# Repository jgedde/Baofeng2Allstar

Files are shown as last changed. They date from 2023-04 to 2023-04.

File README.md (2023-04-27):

# Baofeng2Allstar

This project allows one or two Baofeng HT's to be connected to a Raspberry Pi Allstar node.  One HT can be connected to make a hotspot.  Two can be connected to make a full-duplex hotspot or a mini-repeater for event or emergency use.

The premise behind this project was to make something "plug and play" with no required modifications to either the Baofeng HTs or the Allstar node's USB sound FOB.

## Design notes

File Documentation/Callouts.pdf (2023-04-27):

1 | 2

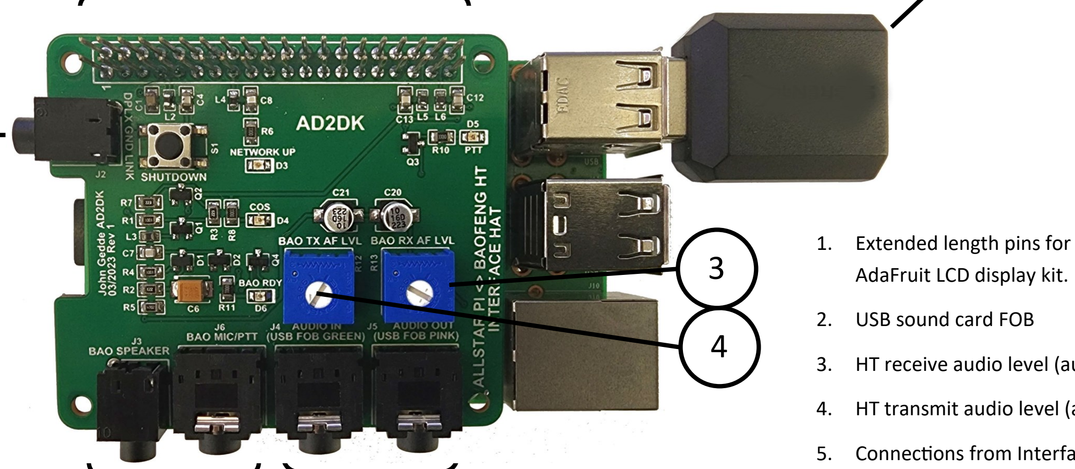
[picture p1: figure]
AdaFruit LCD display kit.; 2. USB sound card FOB

6 | 5

7

1. Extended length pins for additional compatible hats. For example,
3. HT receive audio level (audio level sent from Allstar node.)
4. HT transmit audio level (audio level sent to HT from Allstar node.)
5. Connections from Interface Hat to USB sound card. Both connectors are three conductor (stereo) 1/8 in. (3.5mm) phone jacks.
6. Connections from Interface Hat to one or two HTs. Speaker connector is 2.5mm stereo phono jack. Mic/PTT connector is 1/8 in. (3.5mm) phono jack.
7. Ground link for use with two HTs (see text.) Connector is 2.5mm stereo phone jack.

AD2DK 4/26/2023

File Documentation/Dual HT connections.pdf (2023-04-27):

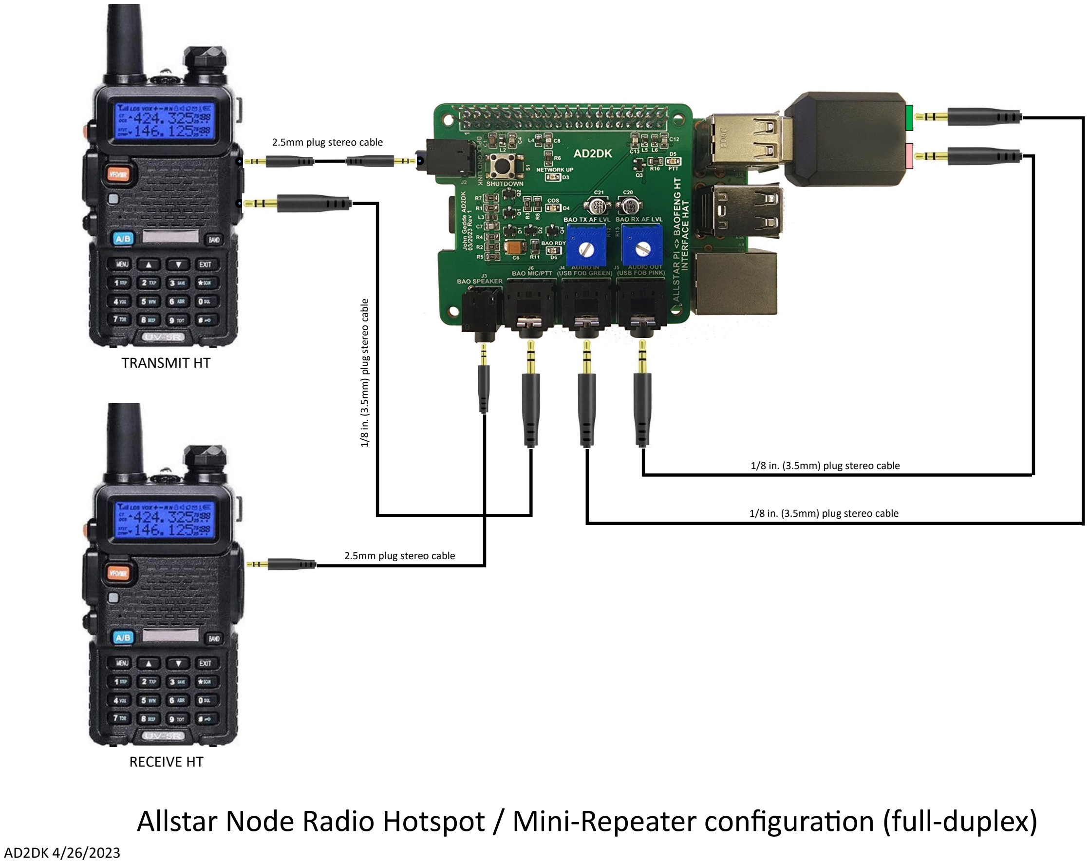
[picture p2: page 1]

1/8 in. (3.5mm) plug stereo cable

1/8 in. (3.5mm) plug stereo cable

1/8 in. (3.5mm) plug stereo cable

2.5mm plug stereo cable

## AD2DK 4/26/2023

# Allstar Node Radio Hotspot / Mini-Repeater configuration (full-duplex)

2.5mm plug stereo cable

## TRANSMIT HT

## RECEIVE HT

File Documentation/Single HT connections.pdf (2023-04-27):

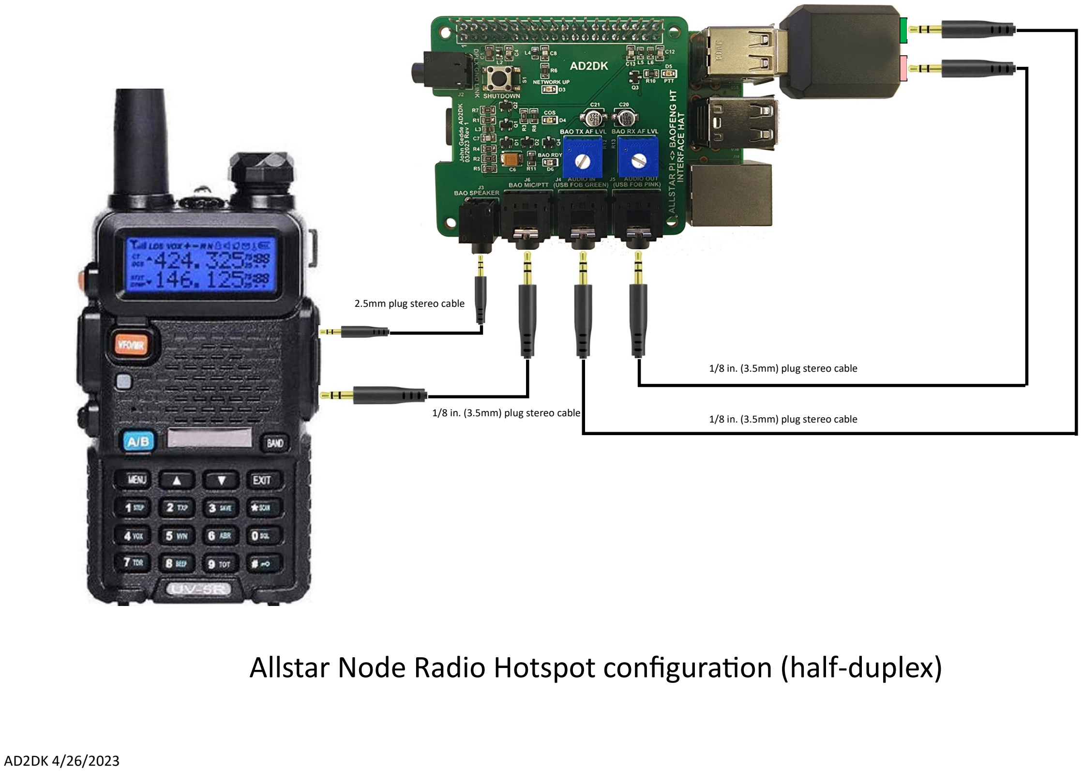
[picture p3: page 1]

1/8 in. (3.5mm) plug stereo cable

1/8 in. (3.5mm) plug stereo cable | 1/8 in. (3.5mm) plug stereo cable

2.5mm plug stereo cable

# Allstar Node Radio Hotspot configuration (half-duplex)

## AD2DK 4/26/2023

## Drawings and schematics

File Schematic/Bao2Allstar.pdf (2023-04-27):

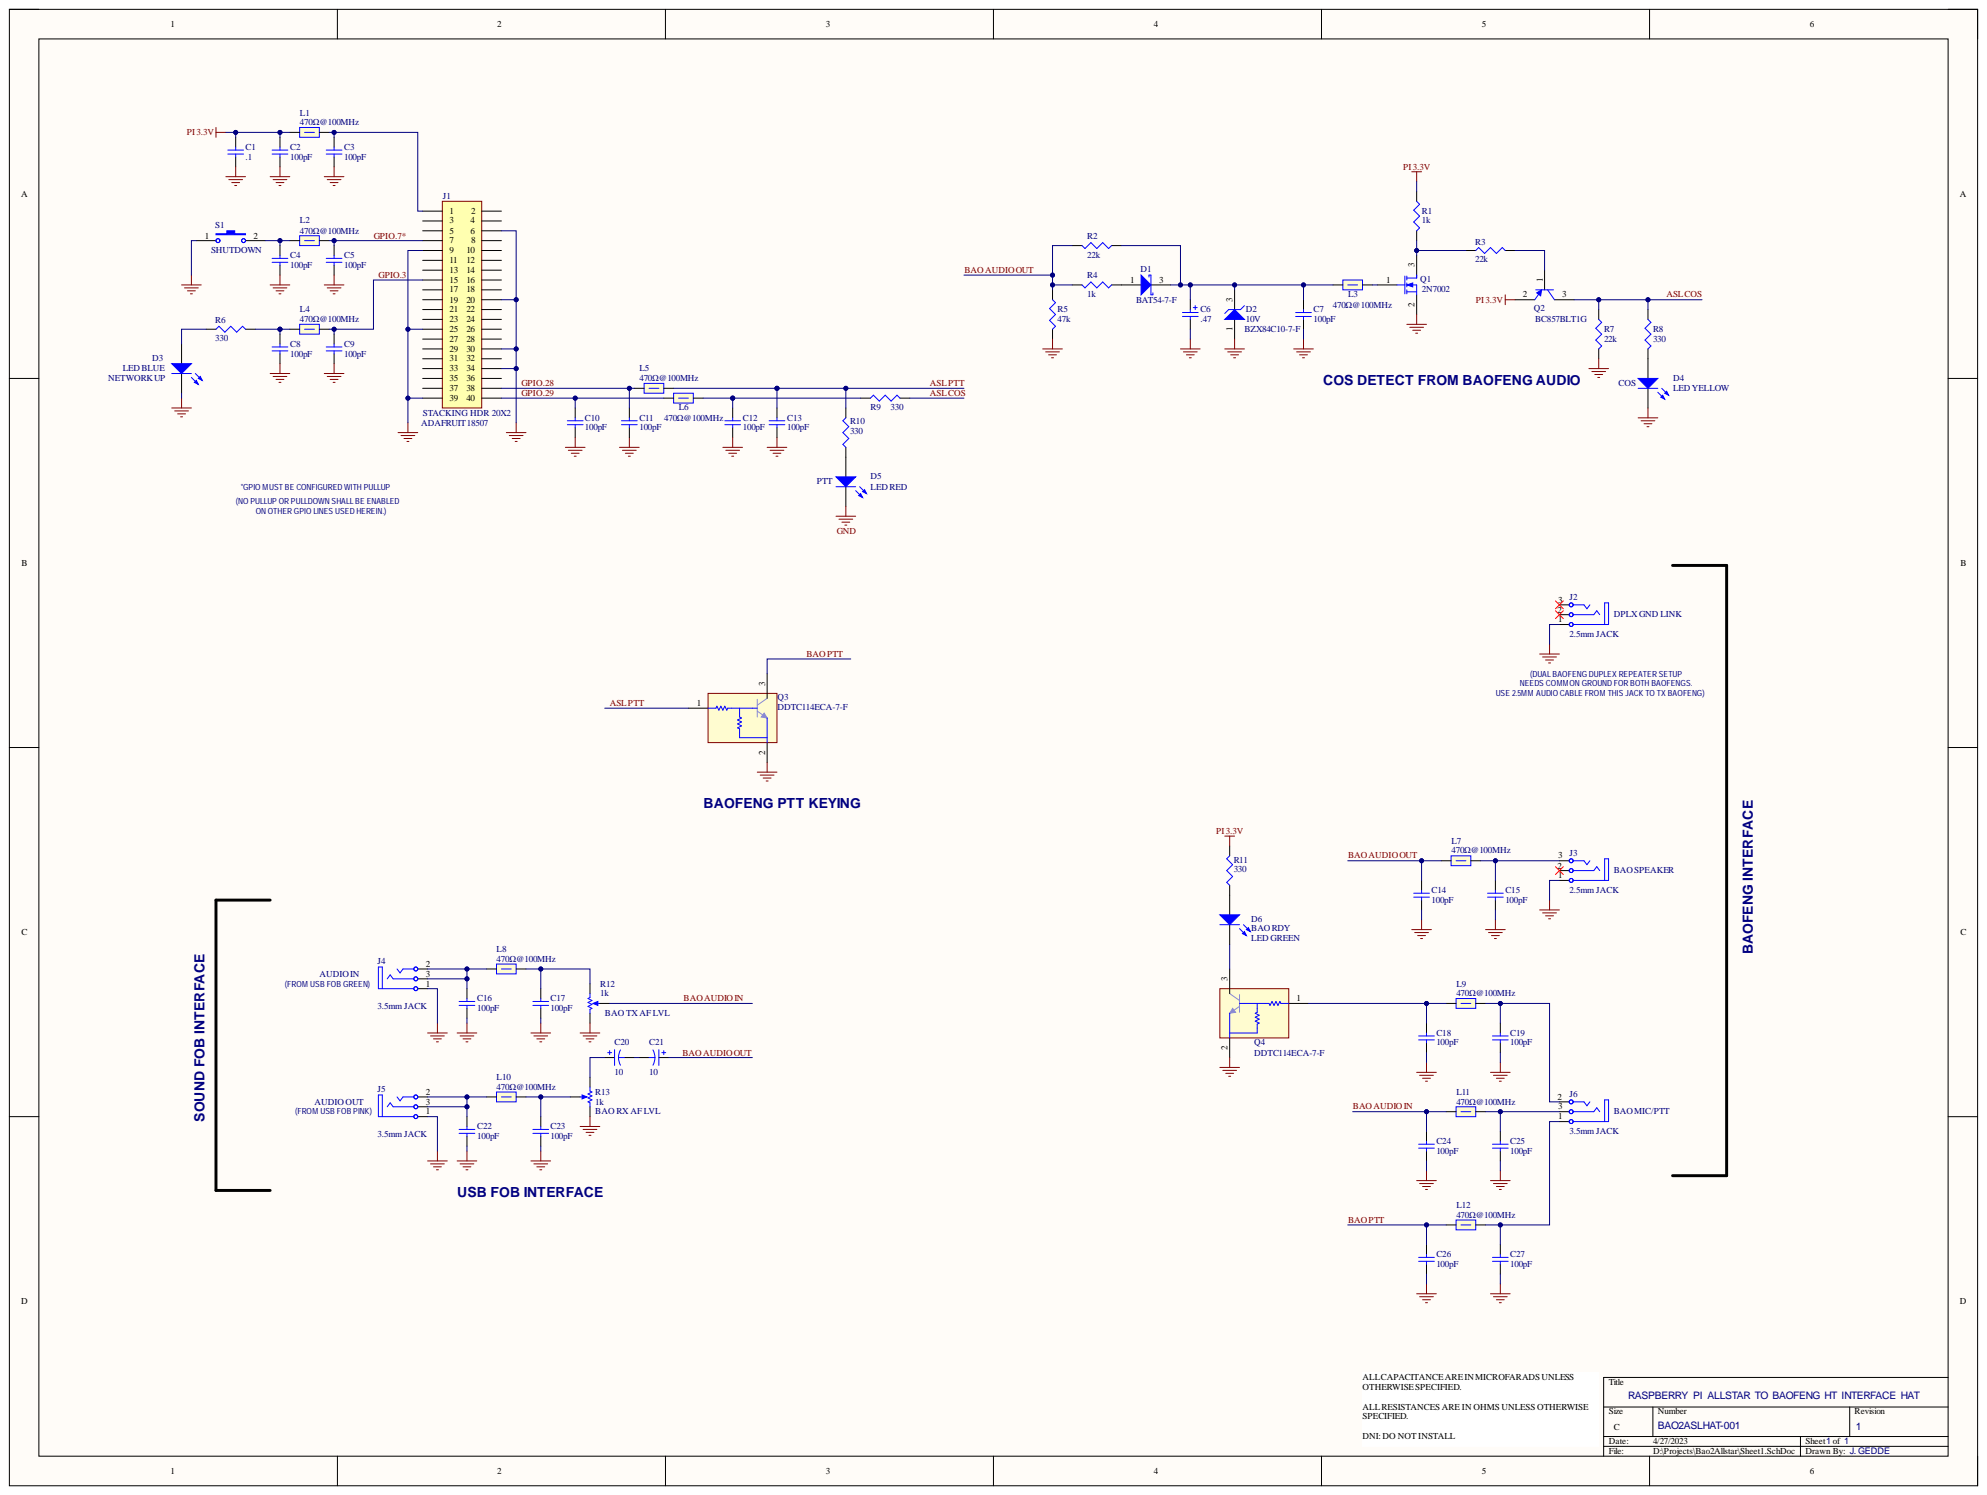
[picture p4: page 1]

*GPIO MUST BE CONFIGURED WITH PULLUP
(NO PULLUP OR PULLDOWN SHALL BE ENABLED
ON OTHER GPIO LINES USED HEREIN.)

(DUAL BAOFENG DUPLEX REPEATER SETUP
NEEDS COMMON GROUND FOR BOTH BAOFENGS.

USE 2.5MM AUDIO CABLE FROM THIS JACK TO TX BAOFENG)

(FROM USB FOB GREEN)

BAO TX AF LVL 100pF

AUDIOOUT
(FROM USB FOB PINK)

Title
RASPBERRY PI ALLSTAR TO BAOFENG HT INTERFACE HAT

ALLRESISTANCES ARE IN OHMS UNLESS OTHERWISE
SPECIFIED.

DNI: DO NOT INSTALL

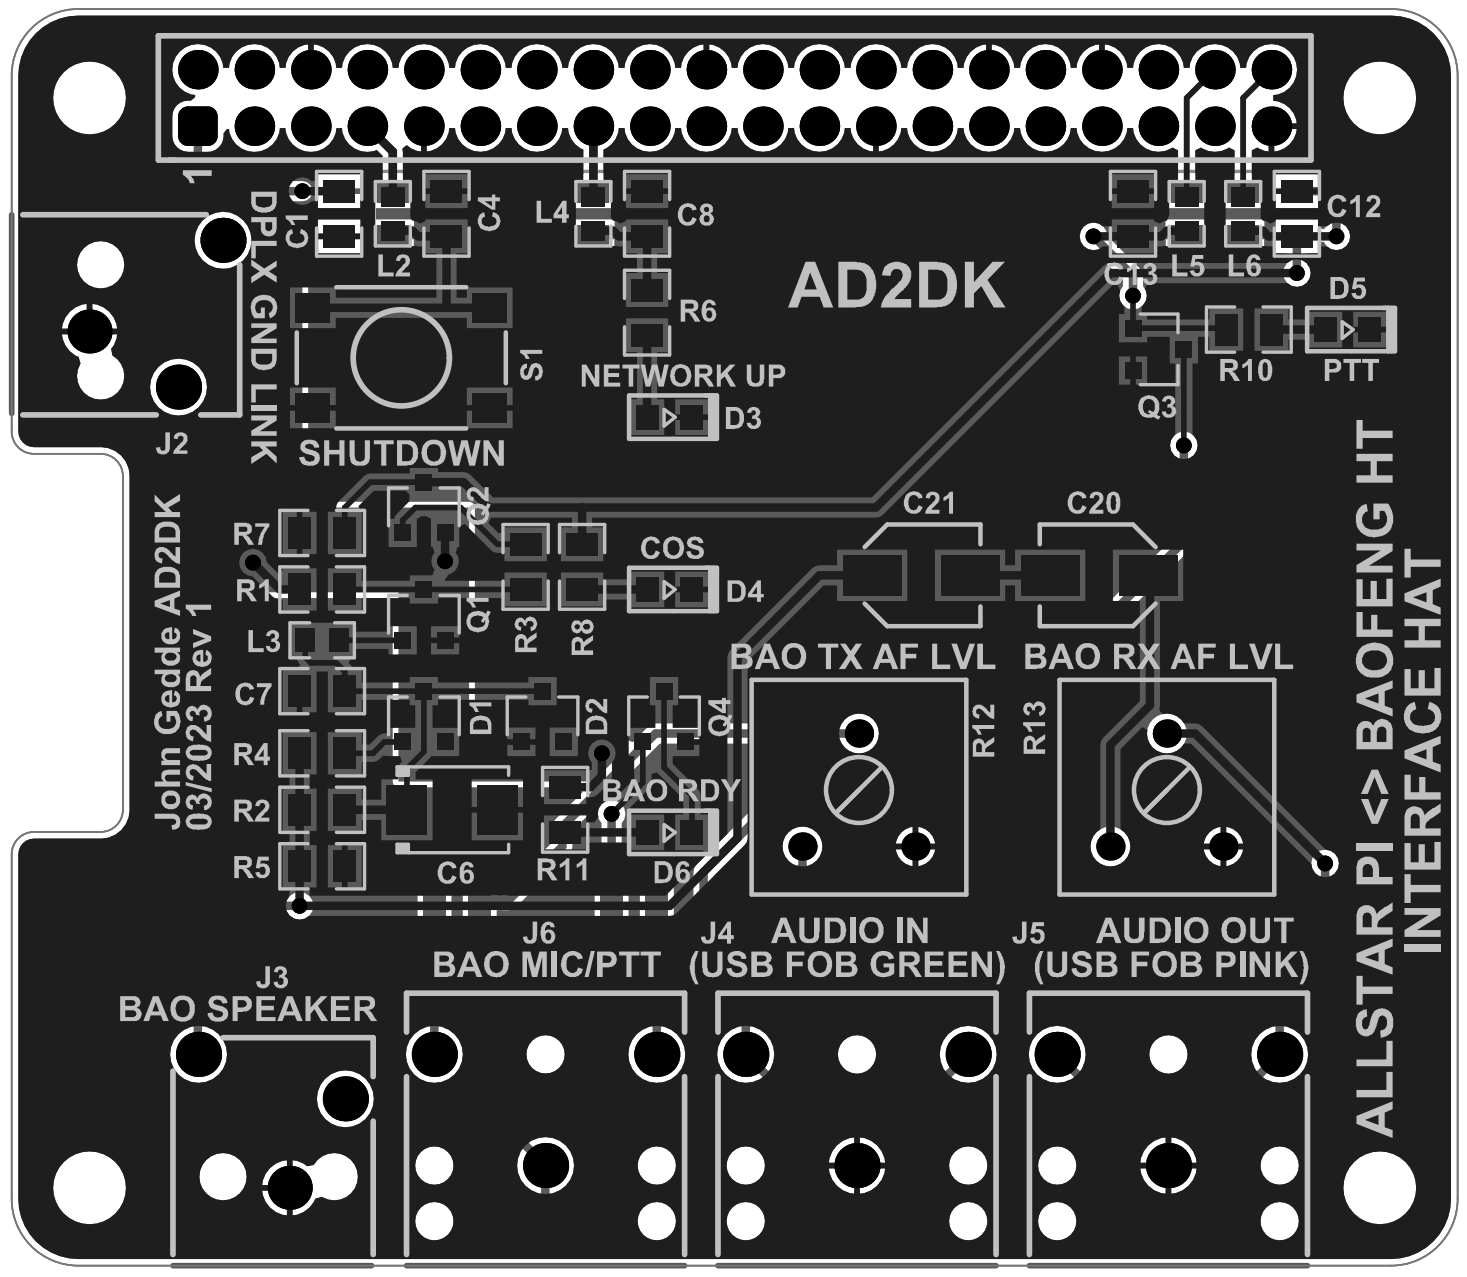
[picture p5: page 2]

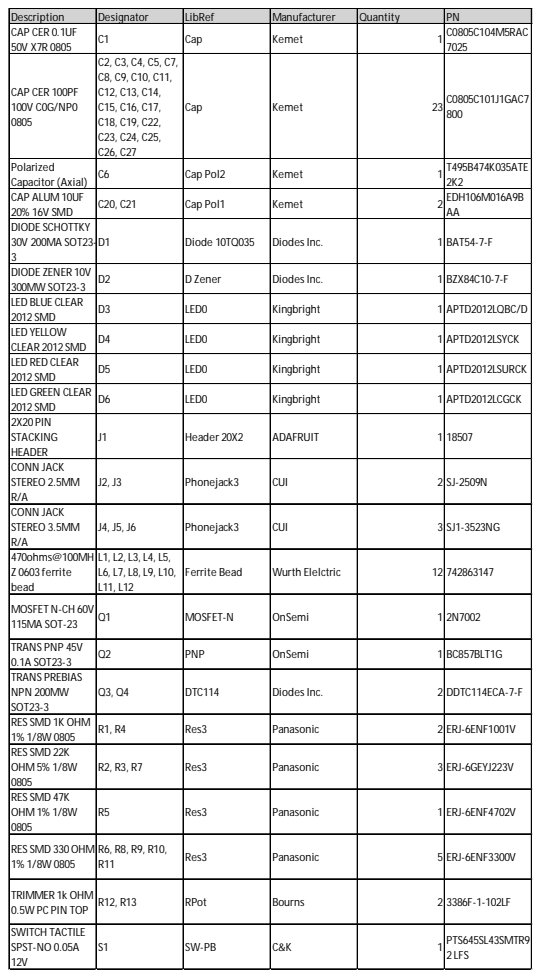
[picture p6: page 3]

Description | Designator | LibRef | Manufacturer | Quantity | PN
CAP CER 0.1UF 50V X7R 0805 | C1 | Cap | Kemet | 1 C0805C104M5RAC | 7025

CAP CER 100PF 100V C0G/NP0 0805 | C2, C3, C4, C5, C7, C8, C9, C10, C11, C12, C13, C14, C15, C16, C17, C18, C19, C22, C23, C24, C25, C26, C27 | Cap | Kemet | 23 C0805C101J1GAC7 | 800

Polarized Capacitor (Axial) | C6 | Cap Pol2 | Kemet | 1 T495B474K035ATE | 2K2

CAP ALUM 10UF 20% 16V SMD | C20, C21 | Cap Pol1 | Kemet | 2 EDH106M016A9B | AA

DIODE SCHOTTKY 30V 200MA SOT23-3 | D1 | Diode 10TQ035 | Diodes Inc. | 1 BAT54-7-F

DIODE ZENER 10V 300MW SOT23-3 | D2 | D Zener | Diodes Inc. | 1 BZX84C10-7-F

LED BLUE CLEAR 2012 SMD | D3 | LED0 | Kingbright | 1 APTD2012LQBC/D

LED YELLOW CLEAR 2012 SMD | D4 | LED0 | Kingbright | 1 APTD2012LSYCK

LED RED CLEAR 2012 SMD | D5 | LED0 | Kingbright | 1 APTD2012LSURCK

LED GREEN CLEAR 2012 SMD | D6 | LED0 | Kingbright | 1 APTD2012LCGCK

2X20 PIN STACKING HEADER | J1 | Header 20X2 | ADAFRUIT | 1 18507

CONN JACK STEREO 2.5MM R/A | J2, J3 | Phonejack3 | CUI | 2 SJ-2509N

CONN JACK STEREO 3.5MM R/A | J4, J5, J6 | Phonejack3 | CUI | 3 SJ1-3523NG

470ohms@100MH Z 0603 ferrite bead | L1, L2, L3, L4, L5, L6, L7, L8, L9, L10, L11, L12 | Ferrite Bead | Wurth Elelctric | 12 742863147

MOSFET N-CH 60V 115MA SOT-23 | Q1 | MOSFET-N | OnSemi | 1 2N7002

TRANS PNP 45V 0.1A SOT23-3 | Q2 | PNP | OnSemi | 1 BC857BLT1G

TRANS PREBIAS NPN 200MW SOT23-3 | Q3, Q4 | DTC114 | Diodes Inc. | 2 DDTC114ECA-7-F

RES SMD 1K OHM 1% 1/8W 0805 | R1, R4 | Res3 | Panasonic | 2 ERJ-6ENF1001V

RES SMD 22K OHM 5% 1/8W 0805 | R2, R3, R7 | Res3 | Panasonic | 3 ERJ-6GEYJ223V

RES SMD 47K OHM 1% 1/8W 0805 | R5 | Res3 | Panasonic | 1 ERJ-6ENF4702V

RES SMD 330OHM 1% 1/8W 0805 | R6, R8, R9, R10, R11 | Res3 | Panasonic | 5 ERJ-6ENF3300V

TRIMMER 1k OHM 0.5W PC PIN TOP | R12, R13 | RPot | Bourns | 2 3386F-1-102LF

SWITCH TACTILE SPST-NO 0.05A 12V | S1 | SW-PB | C&K | 1 PTS645SL43SMTR9 | 2 LFS

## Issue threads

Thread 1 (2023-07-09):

PTT

neilsweb, 2023-07-09:
Hi John,
first of all i would like to thank you for this project, i ordered a board and got everything together but i cannot seem to get the ptt to work "red led" I used some of the instructions from your ASLlcd but i maybe missing something.
regards
neil

jgedde, 2023-07-10:
Please call me at 631-905-8221 to discuss.  You’re the first who has tried it on a new system and I’d like to walk through it with you to wring out the process…

TY,

john

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

neilsweb, 2023-07-10:
Hi John,
Thanks for the reply, I would not be able to ring as i live in the UK and i have only a mobile phone.
All other functions are working, shutdown, blue led for internet connection.
When i am receiving audio from the node if i press the ptt manually i can hear audio. i am assuming the gpio 28 needs some kind of program running in the background to go high/low when i receive audio to activate the ptt, but i may be wrong. I've learnt soldering 0805 and 0603 so it is a good project for me.

regards
neil

neilsweb, 2023-07-11:
Hi John,
I got it all working, i used this link to control the ptt.
https://community.allstarlink.org/t/raspberry-pi3-gpio-tx-rx-status-led/15625/2
maybe in future you can implement it in COSmon has it uses s|t|RPT_TXKEYED.

Thank you very much for creating this i am well happy.

regards
neil

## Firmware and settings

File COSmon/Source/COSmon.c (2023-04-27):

/****************************************************************************
*  Copyright (c)2023 John Gedde (Amateur radio callsign AD2DK)
*  
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
*	This file is part of cosMON:
*	https://github.com/ IT AIN'T THERE YET          
*
*  COSmon.c
*                                                                          
*  Synopsis:	Purpose: COS monitor from Raspberry Pi using Wiring Pi
*				We detect COS from an external radio on the rasp
*				Pi GPIO pins and use it to Key and unkey Allstar COS by
*				calling asterisk commands from asterisk's command line calls.
*				If external COS is stuck high we will automatically unkey COS
*				after COS_TIMEOUT_MS milliseconds.
*
*  Project:	Allstar Link LCD
*                                                                         
*  File Version History:                                                       
*    Date    |      Eng     |               Description
*  ----------+--------------+------------------------------------------------
*  See Below
*  
****************************************************************************/

/* 
	Version History:
	John Gedde Rev 0 02/24/23 Original Version
	John Gedde Rev 1 02/25/23 Added COS timeout feature
	John Gedde Rev 2 02/26/23 Added support of command line options for COS Timeout, 
							  poll timing, GPIO pin select, and help.
	John Gedde Rev 3 02/28/23 Fixed issue with COS timeout on start-up.
	John Gedde Rev 4 03/23/23 Added support for network status LED and shutdown switch
	John Gedde Rev 5 03/24/23 Got rid of command line setuip in favor of conf file.	
*/

#include <stdio.h>
#include <stdlib.h>
#include <wiringPi.h>
#include <string.h>
#include <iniparser.h>
#include <stdint.h>
#include <stdbool.h>

#include "getIP.h"
#include "ini.h"

const char strVersion[]="v1.1";

// This is where COS will come into the Rasppi
#define DEFAULT_EXTCOS_GPIO			29 		// GPIO.29 (pin 40)
#define DEFAULT_LOOP_DELAY			100		// milliseconds	
#define DEFAULT_COS_TIMEOUT_MS		150000	// milliseconds
#define DEFAULT_COS_TIMEOUT_COUNT	(DEFAULT_COS_TIMEOUT_MS / DEFAULT_LOOP_DELAY)
#define DEFAULT_NETWORK_GPIO		3		// GPIO.3 (pin 15)
#define DEFAULT_SHUTDOWN_GPIO		7		// GPIO.7 (pin 7)
#define DEFAULT_NET_CHECK_DIVISOR	20		// every 20 times through the main COS loop
#define DEFAULT_SD_ACTIVATE_COUNT	30      // Must be pressed for 30 times through the main loop

enum
{
	RETVAL_OK=0,
	RETVAL_ILLEGALARG=-1,
	RETVAL_UNEXPECTEDARG=-2,
	RETVAL_BADPARM=-3,
	RETVAL_HELPME=-4
};

static const uint16_t GPIOAllowed[]={0, 1, 2, 3, 4, 5, 6, 7, 21, 22, 23, 24, 25, 26, 27, 28, 29};
static uint16_t networkStatusPin=DEFAULT_NETWORK_GPIO;

/*-----------------------------------------------------------------------------
Function:
	main   
Synopsis:
	Called to check to see if we have an IP address.
Author:
	John Gedde
Inputs:
	None	
Outputs:
	Control gpio Pin
-----------------------------------------------------------------------------*/
static void wifiLightHandler()
{
	char IPaddr[17]={ 0 };
	static uint8_t lastWrite=LOW;
	int IPlen;
		
	getIPaddress(IPaddr);
	IPlen=strlen(IPaddr);
	
	if (IPlen==0 && lastWrite==HIGH)
	{
		digitalWrite(networkStatusPin, LOW);
		lastWrite=HIGH;
	}
	else if ((IPlen!=0) & (lastWrite==LOW))
	{
		digitalWrite(networkStatusPin, HIGH);
		lastWrite = LOW;
	}		
}


//////////////////////////////////////////////////////////////////////////////////
/*-----------------------------------------------------------------------------
Function:
	main   
Synopsis:
	c main function for COSmon
Author:
	John Gedde
Inputs:
	None	
Outputs:
	return val to caller
-----------------------------------------------------------------------------*/
int main(void)
{
	bool 			LastCOSState;
	bool 			CurrCOSState;
	uint16_t 		netCheckDivisor;
	uint16_t 		ExtCOSPin;
	uint16_t 		TimeoutCountCOS;
	uint16_t 		TimeoutCount;	
	uint16_t	 	LoopDelayMs;
	uint32_t		TimeoutMs;
	float 			tempval;
	bool 			networkStatusOn;
	bool 			shutdownSwitchEnable;
	bool			COStimeoutEnable;
	uint16_t 		shutdownSwitchPin;
	uint16_t		SDswitchActivateCount;
	uint16_t		SDswitchPressedCount;
		
	initIni("/etc/COSmon.conf");
	
	ExtCOSPin=				iniparser_getint(ini, "gpio:gpio_COS", DEFAULT_EXTCOS_GPIO);
	networkStatusPin=		iniparser_getint(ini, "gpio:gpio_network", DEFAULT_NETWORK_GPIO);
	shutdownSwitchPin=		iniparser_getint(ini, "gpio:gpio_shutdown", DEFAULT_SHUTDOWN_GPIO);
	networkStatusOn=		iniparser_getboolean(ini, "functions:enable_network_status_LED", 0);
	shutdownSwitchEnable=	iniparser_getboolean(ini, "functions:enable_shutdown_switch", 0);
	LoopDelayMs=			iniparser_getint(ini, "COS settings:COS_poll_loop_interval_ms", DEFAULT_LOOP_DELAY);
	TimeoutMs=				iniparser_getint(ini, "COS settings:COS_timeout_ms", DEFAULT_COS_TIMEOUT_MS);
	COStimeoutEnable=		iniparser_getboolean(ini, "COS settings:COS_timeout_enable", 1);
	netCheckDivisor=		iniparser_getint(ini, "COS settings:network_check_divisor", DEFAULT_NET_CHECK_DIVISOR);
	SDswitchActivateCount=	iniparser_getint(ini, "COS settings:shutdown_switch_activate_count", DEFAULT_SD_ACTIVATE_COUNT);

	const char KeyCmd[]="asterisk -rx \"susb tune menu-support K\"";
	const char UnkeyCmd[]="asterisk -rx \"susb tune menu-support k\"";
	
	unsigned int loopCount=0;
	
	if (access("/var/run/asterisk.ctl", F_OK) != 0)
	{
		fprintf(stderr, "\nAsterisk needs to be running first!  Exiting\n\n");
		exit(-1);
	}
		
	// Printf Config
	printf("\nCOSmon version %s\n", strVersion);
	printf("Config:\n");
	printf("\tCOS GPIO number: %u\n", ExtCOSPin);
	if (COStimeoutEnable==0)
		printf("\tCOS timeout disabled\n");
	else	
		printf("\tCOS timeout (ms): %u\n", TimeoutMs);
	printf("\tCOS check loop delay (ms): %u\n", LoopDelayMs);	
	printf("\tShutdown switch: %s\n", (shutdownSwitchEnable ? "ENABLED" : "DISABLED"));
	printf("\tNetwork connected Indicator: %s\n", (networkStatusOn ? "ENABLED" : "DISABLED"));
	printf("\tNetwork status GPIO number: %u\n", networkStatusPin);
	printf("\tShutdwon switch GPIO number: %d\n", shutdownSwitchPin);
	printf("\tNetwork check divisor: %u\n", netCheckDivisor);
	printf("\n");

	// Compute timeout count
	tempval=(float)TimeoutMs/(float)LoopDelayMs;
	tempval += 0.5;
	TimeoutCountCOS=(int)tempval;

	// Initialize so we don't get an immediate timeout on startup.
	TimeoutCount=-1;

	// initialize wiringPi and setup pins
	wiringPiSetup();
	pinMode(ExtCOSPin, INPUT);
	pinMode(networkStatusPin, OUTPUT);
	digitalWrite(networkStatusPin, LOW);
	pinMode(shutdownSwitchPin, INPUT);
	pullUpDnControl(shutdownSwitchPin, PUD_UP) ;

	printf("COSmon running\n");

	// Initialize change detection vars
	LastCOSState=digitalRead(ExtCOSPin);
	
	// Unkey asterisk
	system(UnkeyCmd);

	for(;;)  // forever
	{
		CurrCOSState=digitalRead(ExtCOSPin);
		
		// check for change is COS pin state
		if (LastCOSState!=CurrCOSState)
		{
			// Something has changed...
			// (we only do something when COS changes so we don't continually
			// call asterisk for no reason every time throgh the loop.
			// this seems to cause loading issues.)

			// Read COS pin state
			if (CurrCOSState==HIGH)
			{
				// Key asterisk
				system(KeyCmd);
				TimeoutCount = TimeoutCountCOS;
			}
			else
			{
				// Unkey asterisk
				system(UnkeyCmd);
			}
			LastCOSState=CurrCOSState;
		}
		else if (COStimeoutEnable)
		{
			// Nothing has changed.  Check for COS stuck high.
			if (TimeoutCount>0 && CurrCOSState==HIGH)
				TimeoutCount--;
			else if (TimeoutCount==0)
			{
				// Timeout has been reached, unkey the node.  Only once...  When count=0.  
				printf("COS Timeout\n");
				system(UnkeyCmd);
				TimeoutCount=-1;
			}
		}
		
		// Handle shutdown switch.  Needs to be pressed for SDswitchActivateCount times through the loop
		if (digitalRead(shutdownSwitchPin)==LOW)	// Active low
		{
			SDswitchPressedCount++;
			if (SDswitchPressedCount>SDswitchActivateCount)
			{
				// Turn of network light as acknokwledge
				digitalWrite(networkStatusPin, HIGH);
				printf("Shutting down!\n");
				system("/usr/local/sbin/astdn.sh");
				delay(5000);
				system("/usr/bin/poweroff");
				break;
			}
			
		}
		else
			SDswitchPressedCount=0;
		
		
		// if enabled check network status, but only netCheckDivisor times through the main loop
		if ((loopCount++ % netCheckDivisor)==0 && networkStatusOn)  
			wifiLightHandler();
		delay(LoopDelayMs);
	}
	
	// ......Can't actually get here....
	// Close out ini
	iniparser_freedict(ini);

	return RETVAL_OK;
}

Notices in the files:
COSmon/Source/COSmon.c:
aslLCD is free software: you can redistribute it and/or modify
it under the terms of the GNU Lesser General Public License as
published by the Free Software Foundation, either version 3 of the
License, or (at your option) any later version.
